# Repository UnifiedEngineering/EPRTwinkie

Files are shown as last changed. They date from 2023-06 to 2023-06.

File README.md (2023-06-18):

# EPRTwinkie
EPR (USB PD 3.1) capable PD sniffer based on Google Twinkie (https://www.chromium.org/chromium-os/twinkie) and inspired by https://github.com/dojoe/Twonkie and https://github.com/gregdavill/PD-sniffer

This hardware will run BMC USBPD capture with unmodified Twinkie firmware but VBUS/VCONN voltage and current readout won't work without some minor modifications:

INA231 bus voltage location is register 0x02, INA237 location is 0x05

INA231 bus voltage multiplier is 2.5mV/LSB, INA237 is 3.125mV/LSB

INA231 current location is register 0x04, INA237 location is 0x07

INA231 shunt calibration location is register 0x05, INA237 location is 0x02

Shunt calibration needs to be changed to 0x6000 for INA237 with 30mOhm resistors as used in this design

Alert and mask settings are also different but I haven't touched those yet.

The Total Phase PD Analyzer firmware can be patched to support the INA237 (tested with pda-firmware-v1.11.img, sha256 188ff949bfdff9008c31673b82b8075096c83ed49956b9d1404533d28acdc3b5) using [this patch file](pda-firmware-v1.11.img.hex.patch). Note that the diff was done on a hex representation created using ´xxd -c1´. If someone has a more straight-forward way of creating readable binary diffs I'd love to hear about it.

Boards
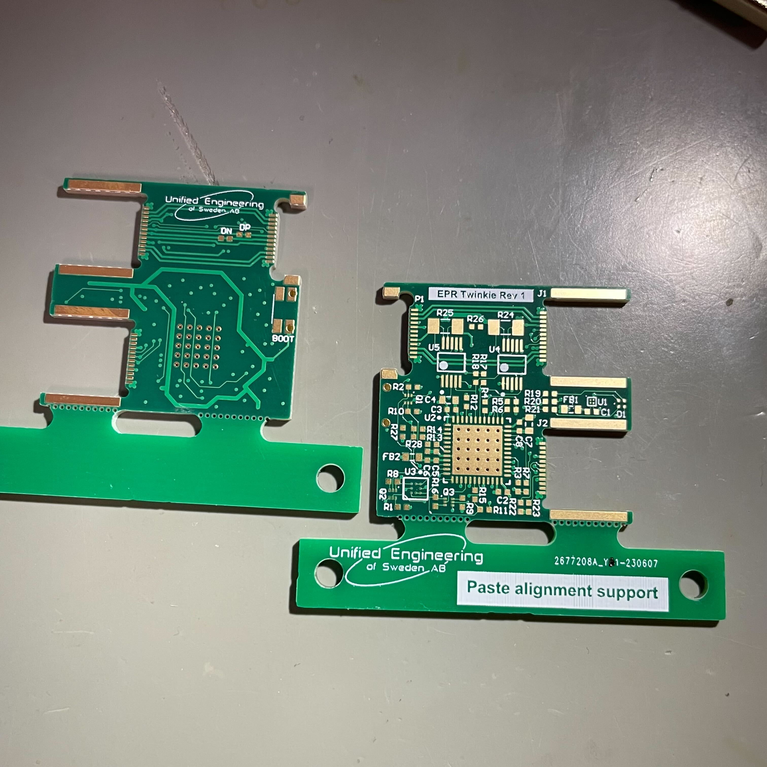
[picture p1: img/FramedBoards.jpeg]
Framed boards


Special variant which enables the use of a computer with limited supply capabilities in combination with a USB PD adapter to supply a USB PD capable USB peripheral
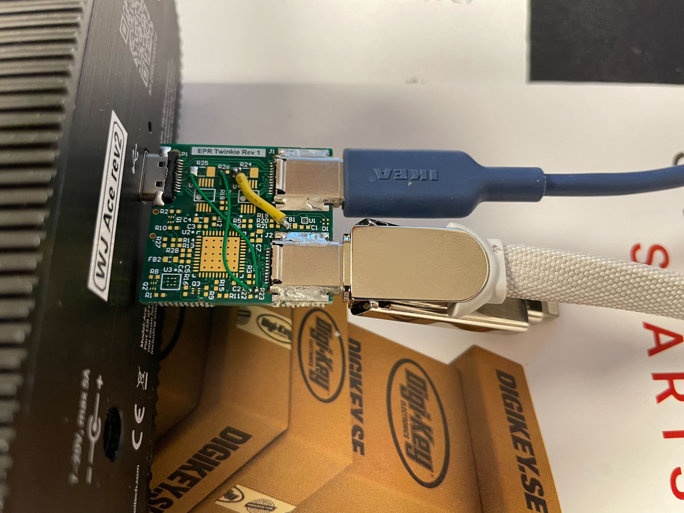
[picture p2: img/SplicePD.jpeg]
PD splice variant


Fully assembled EPR Twinkie boards
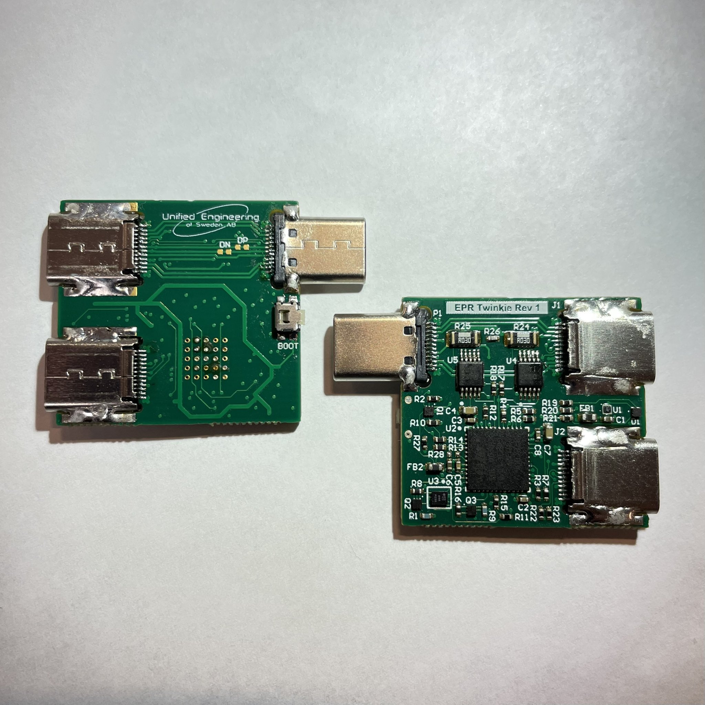
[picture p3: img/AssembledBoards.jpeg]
Fully assembled boards


Example EPR capture (don't have any devices capable of >28V yet)
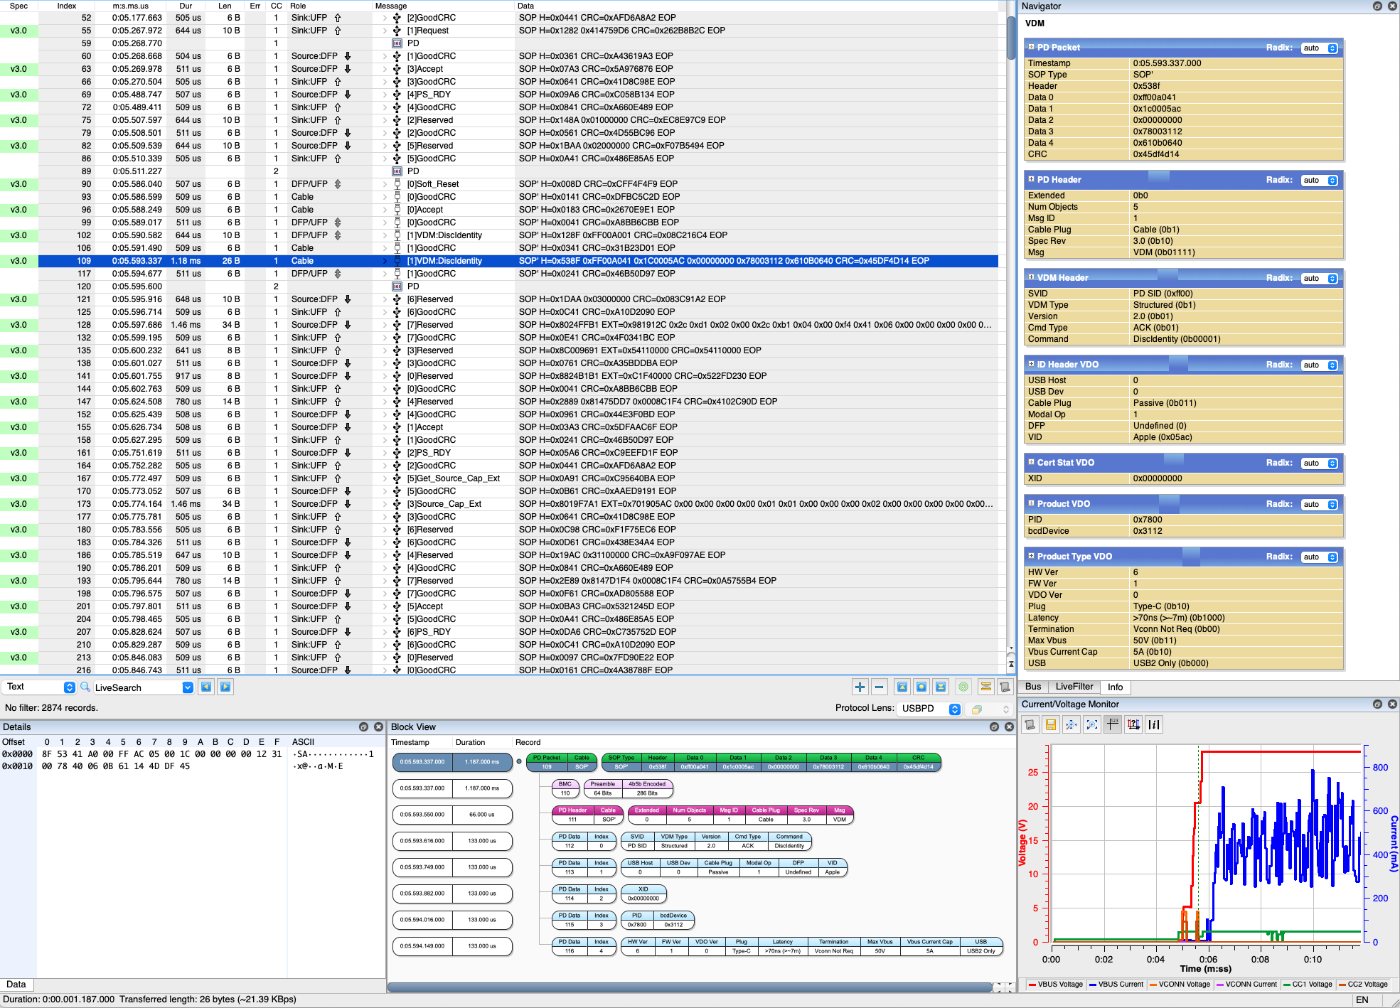
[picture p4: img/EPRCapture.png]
EPR capture screenshot


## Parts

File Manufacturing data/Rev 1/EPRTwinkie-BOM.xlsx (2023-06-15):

Designator | Quantity | Name | Value | Manufacturer 1 | Manufacturer Part Number 1 | Supplier 1 | Supplier Part Number 1
BOOT | 1 | 434331013822 |  | Wurth Electronics | 434331013822 | Mouser | 710-434331013822
C1, C6 | 2 | 1005 | 1u | TDK | C1005X5R1C105K050BC
C2, C3, C8 | 3 | 1005 | 100n | TDK | C1005X7R1E104K050BB | Newark | 79Y4222
C4, C7 | 2 | 1608 | 4u7 | TDK | C1005X5R1A475K050BC | Newark | 27AC3397
C5 | 1 | 1005 | 10n | Yageo | CC0402KRX7R7BB103 | Newark | 68R4639
D1 | 1 | UHD111A |  | Wolfspeed | UHD111A-FKA-C3K23E1L3VG5ZB3Z3 | Mouser | 941-UHD1AA3K3E3V53Z3
FB1, FB2 | 2 | 1608 | 600R | Murata | BLM18KG601SN1D | Newark | 55R1514
J1, J2 | 2 | USB4070-30-C_REVC5 |  | Global Connector Technology | USB4070-30-C | Newark | 64AH9090
P1 | 1 | USB4151-GF-C_REVA |  | Global Connector Technology | USB4151-GF-C | Newark | 86AH2023
Q1, Q2, Q3 | 3 | PMDXB600UNE |  | Nexperia | PMDXB600UNEZ | Arrow Electronics | PMDXB600UNEZ
R1, R9 | 2 | 1005 | 200R | Panasonic | ERJ-2RKF2000X | Newark | 12AC0972
R2, R10 | 2 | 1005 | 390k | Panasonic | ERJ-2RKF3903X | Newark | 53W8365
R3, R11 | 2 | 1005 | 1k | Panasonic | ERJ-2RKF1001X | Newark | 90W2948
R4, R12, R22, R23 | 4 | 1005 | 5k1 | Panasonic | ERJ-2RKF5101X | Newark | 53W4395
R5, R13 | 2 | 1005 | 4k7 | Panasonic | ERJ-2RKF4701X | Newark | 85Y8344
R6, R14 | 2 | 1005 | 12k | Panasonic | ERJ-2RKF1202X | Newark | 11AC3062
R7, R15 | 2 | 1005 | 36k | Panasonic | ERJ-2RKF3602X | Newark | 53W4343
R8, R16 | 2 | 1005 | 100R | Panasonic | ERJ-2RKF1000X | Newark | 85Y8050
R17, R18 | 2 | 1005 | 2k2 | Panasonic | ERJ-2RKF2201X | Newark | 90W3005
R19 | 1 | 1005 | 820R | Panasonic | ERJ-2RKF8200X | Newark | 44AC2418
R20 | 1 | 1005 | 620R | Panasonic | ERJ-2RKF6200X | Newark | 53W4433
R21 | 1 | 1005 | 560R | Panasonic | ERJ-2RKF5600X | Newark | 64R5292
R24, R25 | 2 | 3216 | 30m | Yageo | PE1206FRE470R03L | Digi-Key | 13-PE1206FRE470R03LCT-ND
R26 | 1 | 1005 | 0R | Panasonic | ERJ-2GE0R00X | Newark | 63W0591
R27 | 1 | 1005 | 100k | Panasonic | ERJ-2RKF1003X | Newark | 25AC9011
R28 | 1 | 1005 | NM
U1 | 1 | NCP167BFCT330T2G |  | ON Semiconductor | NCP167BFCT330T2G | Arrow Electronics | NCP167BFCT330T2G
U2 | 1 | STM32F072CBU6 |  | STMicroelectronics | STM32F072CBU6 | Farnell | 2432095
U3 | 1 | AD8606ACBZ-REEL7 |  | Analog Devices | AD8606ACBZ-REEL7 | Arrow Electronics | AD8606ACBZ-REEL7
U4, U5 | 2 | INA237AIDGSR |  | Texas Instruments | INA237AIDGSR | Mouser | 595-INA237AIDGSR

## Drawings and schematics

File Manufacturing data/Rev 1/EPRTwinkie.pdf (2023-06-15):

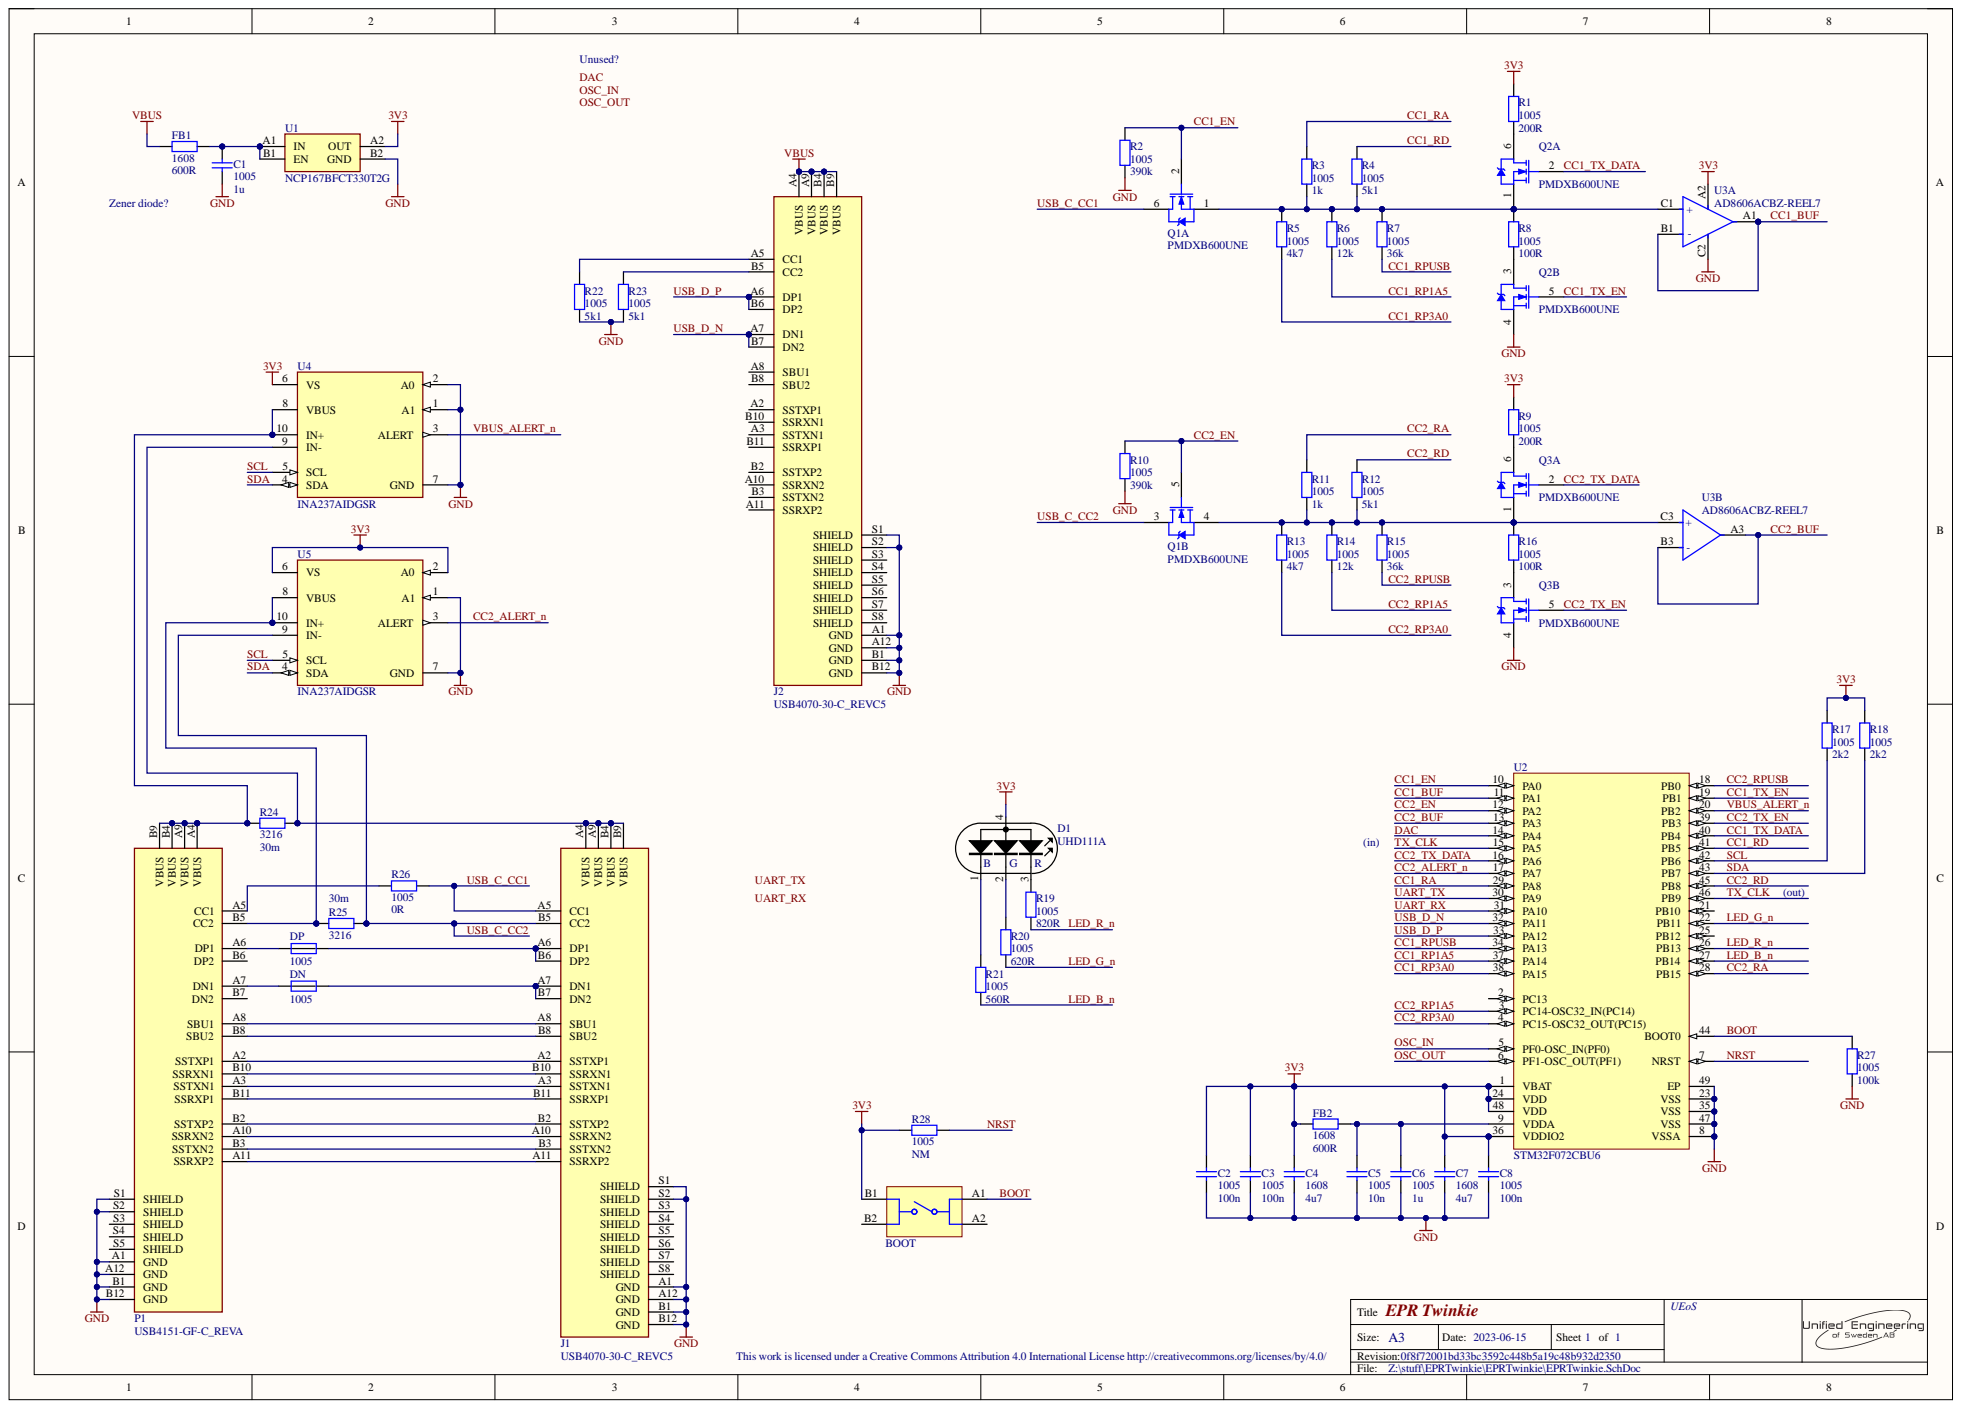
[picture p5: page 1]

SCL | SCL 5

VBUS A4 VBUS A9 VBUS B4 VBUS B9

Revision:
Z:\stuff\EPRTwinkie\EPRTwinkie\EPRTwinkie.SchDoc

This work is licensed under a Creative Commons Attribution 4.0 International License http://creativecommons.org/licenses/by/4.0/

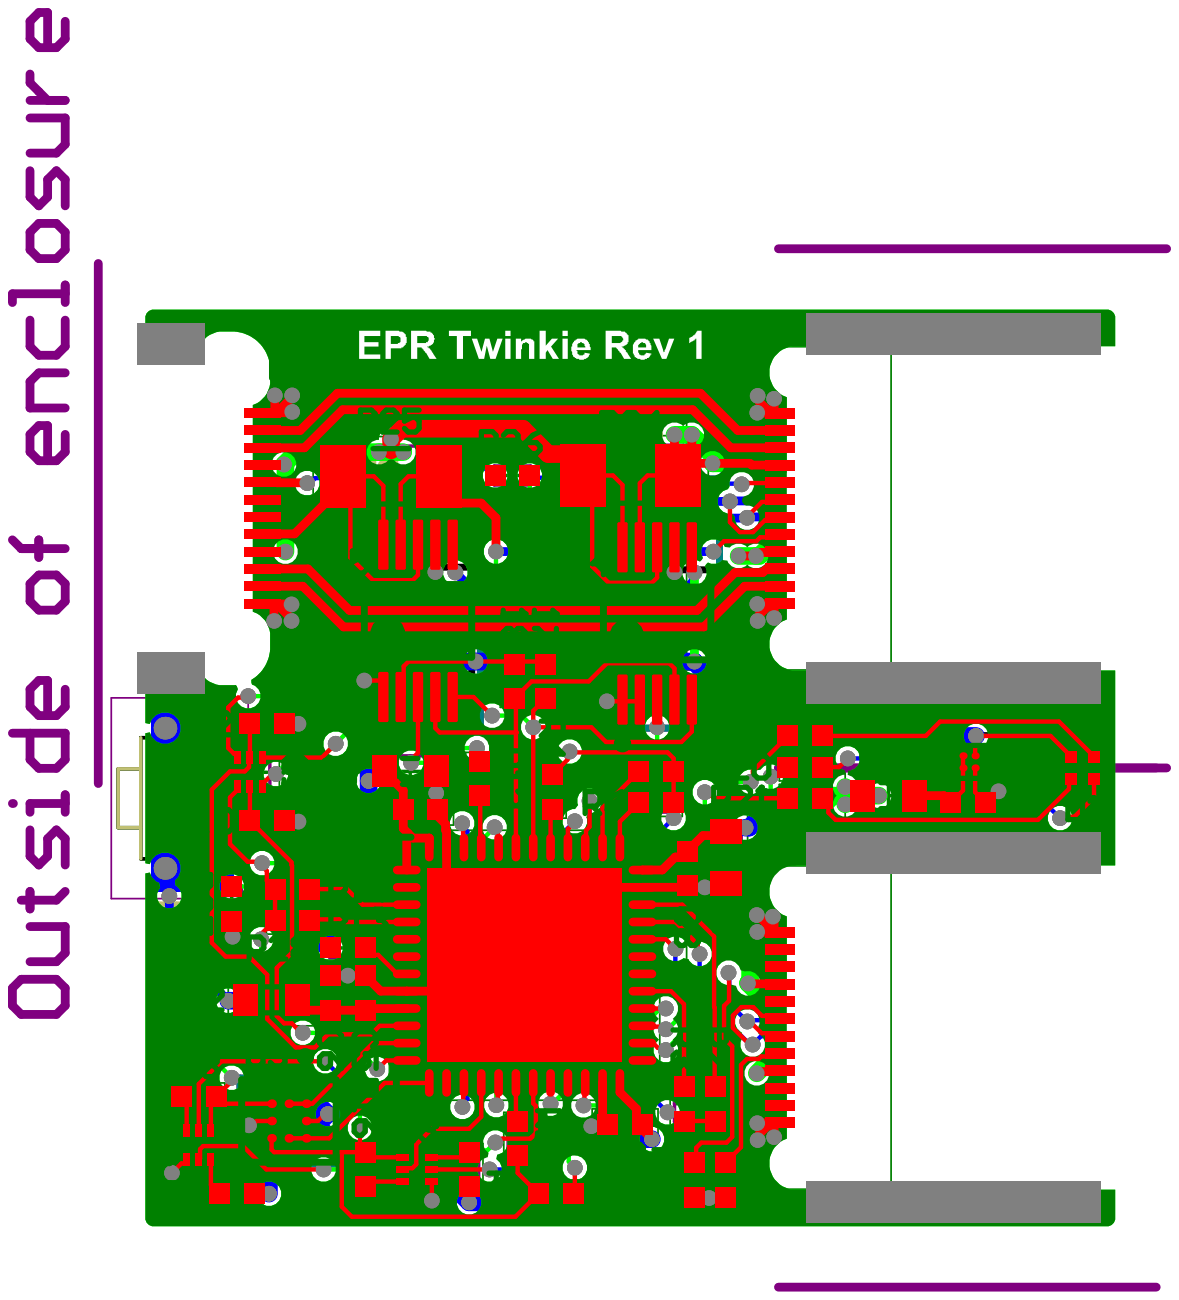
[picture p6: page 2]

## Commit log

2023-06-15 PCB Rev 1
    [1005.PcbLib, 1608.PcbLib, 3216.PcbLib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]
2023-06-15 Add manufacturing data for Rev 1
    [EPRTwinkie-BOM.xlsx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]
